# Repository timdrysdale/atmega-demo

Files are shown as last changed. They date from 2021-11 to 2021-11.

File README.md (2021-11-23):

# atmega-demo
PCB to demonstrate atmega microcontroller together with ACS712 and temperature sensor.

## Purpose

This board will be used to monitor power consumption and temperature in remote lab boxes.

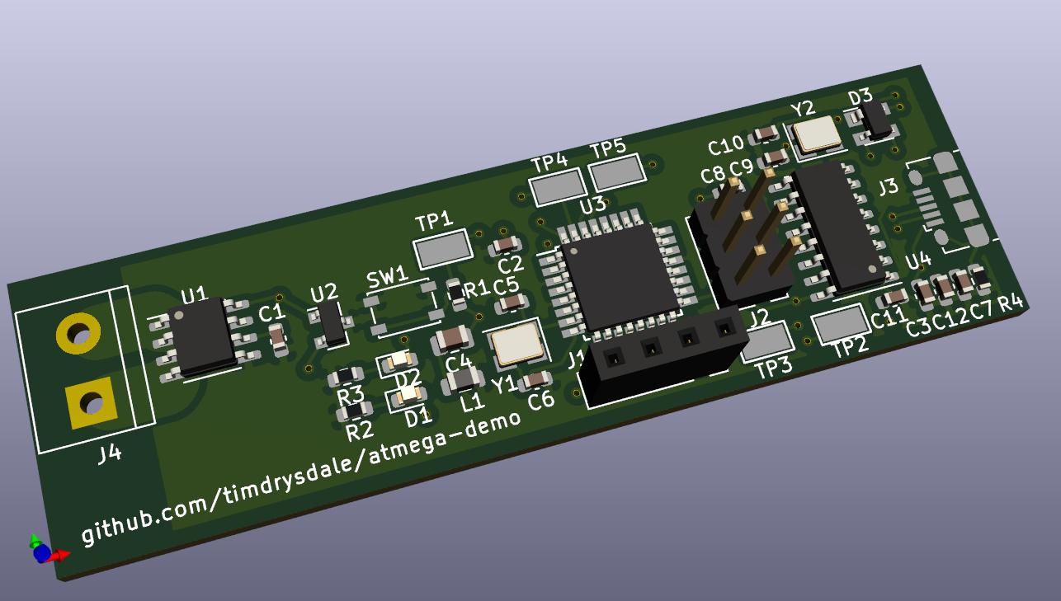
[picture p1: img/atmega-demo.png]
atemga


## Schematic

The key components are an Atmega328P, a CH340 USB transceiver, an ACS712 current sensor and a simple analog temperature sensor. DTR reset is enabled to support re-programming over USB, while ICSP header is supplied for initial programming. Both CH340 and Atmega are using 12MHz crystals, which yields 0.1% baud rate error at 57600 baud for the Atmega.

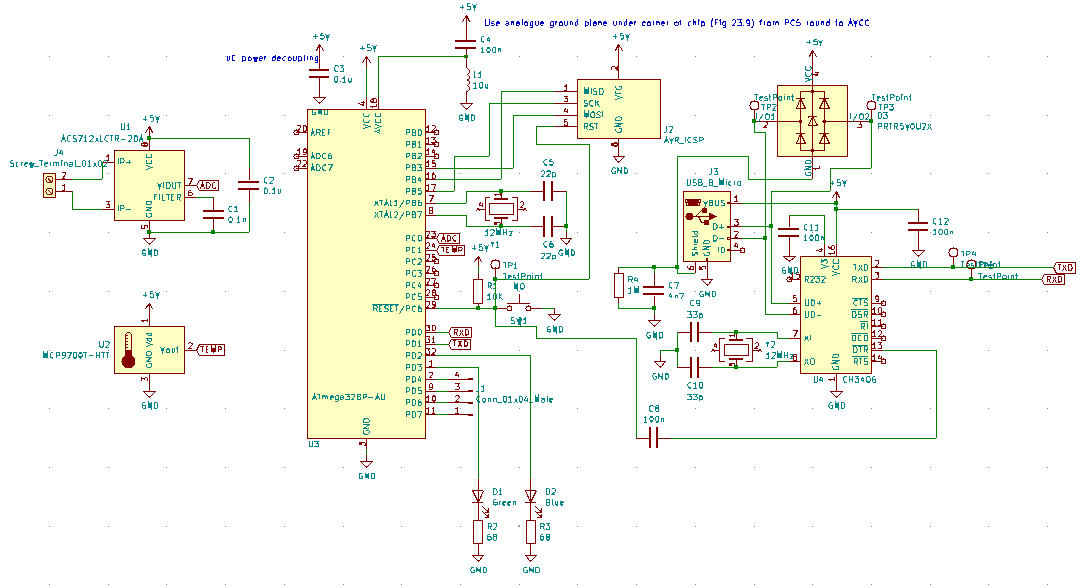
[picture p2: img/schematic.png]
schematic


## BOM

|Comment |Designator |Footprint |LCSC |
|---|---|---|---|
|0.1n |C1 |Capacitor_SMD:C_0603_1608Metric |C100040 |
|100n |C8,C11,C12 |Capacitor_SMD:C_0603_1608Metric |C14663  |
|0.1u |C2,C3 |Capacitor_SMD:C_0603_1608Metric |C14663  |
|100n |C4 |Capacitor_SMD:C_0805_2012Metric |C49678  |
|22p |C5,C6 |Capacitor_SMD:C_0603_1608Metric |C1653 |
|4n7 |C7 |Capacitor_SMD:C_0603_1608Metric |C53987  |
|33p |C9,C10 |Capacitor_SMD:C_0603_1608Metric |C1663 |
|Green |D1 |LED_SMD:LED_0603_1608Metric |C72043  |
|Blue |D2 |LED_SMD:LED_0603_1608Metric |C72043  |
|PRTR5V0U2X |D3 |Package_TO_SOT_SMD:SOT-143 |C2827688|
|Conn_01x04_Male |J1 |Connector_PinSocket_2.54mm:PinSocket_1x04_P2.54mm_Vertical| |
|AVR_ICSP |J2 |Connector_PinHeader_2.54mm:PinHeader_2x03_P2.54mm_Vertical| |
|USB_B_Micro |J3 |Connector_USB:USB_Micro-B_Amphenol_10118194_Horizontal |C132563 |
|Screw_Terminal_01x02|J4 |TerminalBlock:TerminalBlock_bornier-2_P5.08mm | |
|10u |L1 |Inductor_SMD:L_0805_2012Metric |C1046 |
|10K |R1 |Resistor_SMD:R_0603_1608Metric |C25804  |
|68 |R2,R3 |Resistor_SMD:R_0603_1608Metric |C27592  |
|1M |R4 |Resistor_SMD:R_0603_1608Metric |C22935  |
|NO |SW1 |Button_Switch_SMD:SW_SPST_PTS810 |C116501 |
|TestPoint |TP1,TP2,TP3,TP4,TP5|TestPoint:TestPoint_Keystone_5015_Micro-Minature |C238130 |
|ACS712xLCTR-20A |U1 |Package_SO:SOIC-8_3.9x4.9mm_P1.27mm |C10681  |
|MCP9700T-HTT |U2 |Package_TO_SOT_SMD:SOT-23 |C150830 |
|ATmega328P-AU |U3 |Package_QFP:TQFP-32_7x7mm_P0.8mm |C14877  |
|CH340G |U4 |Package_SO:SOIC-16_3.9x9.9mm_P1.27mm |C14267  |
|12MHz |Y1,Y2 |Crystal:Crystal_SMD_3225-4Pin_3.2x2.5mm |C97242  |

## Production

### DFM

The design for manufacture showed a couple of small issues:

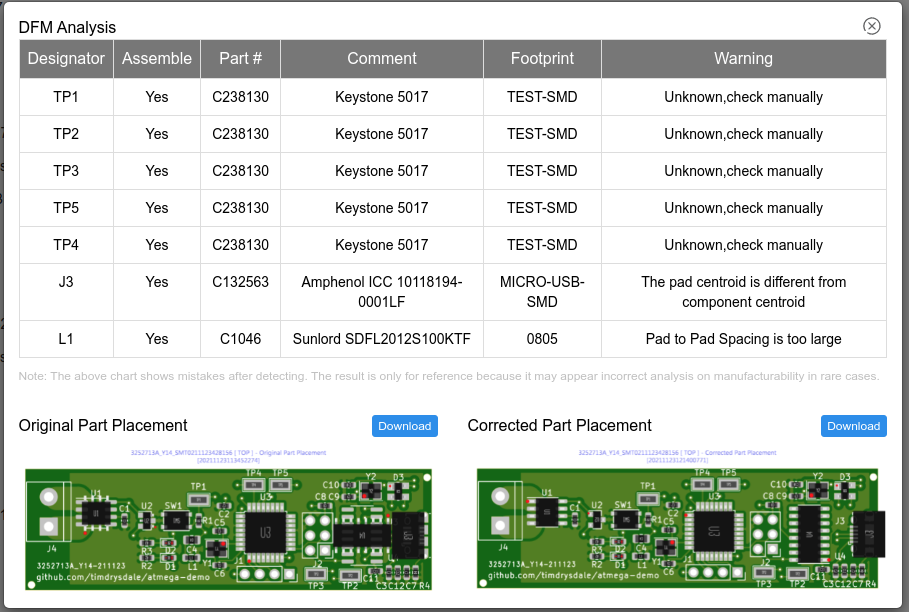
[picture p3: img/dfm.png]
dfm


The parts placement as shown on upload (known to disply with incorrect rotations):

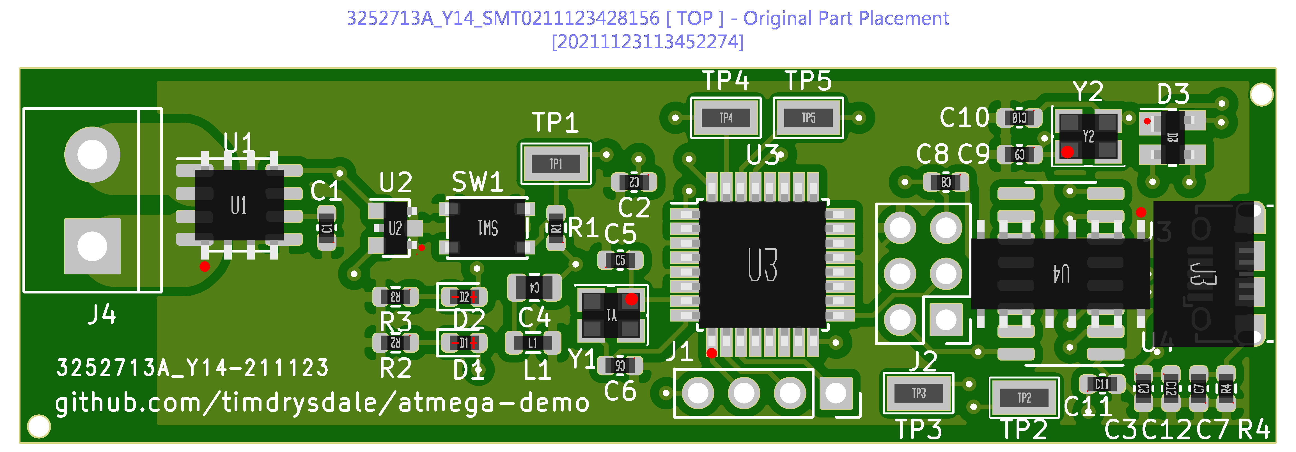
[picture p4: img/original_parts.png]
original_parts


The corrected placement after processing by JLCPCB (parts now oriented the same as the 3D output from KiCAD:

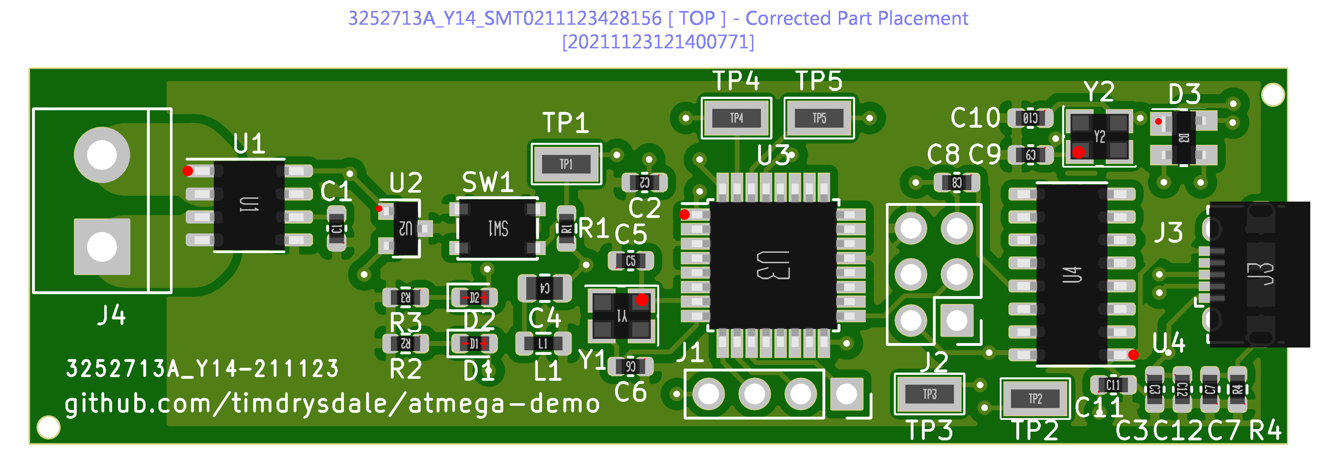
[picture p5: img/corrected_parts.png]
corrected_parts


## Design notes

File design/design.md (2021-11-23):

# DESIGN DESCRIPTION TEMPLATE

## Background

This board is to demonstrate self-assembled Atmega328P circuit.

## Specification

Arduino with USB programming, current sensor, and temp sensor.

Possibly reverse polarity protection, and/or level shifter and external connections headers.

### Design tradeoffs

Note any issues which could be handled in more than one way and justify the approach taken?

### Design for assembly

How will you put it together e.g. if using cable connections, how will these be manufactured?

### Design for reliability

Things go wrong with assembly and usage, even with the best of staff working on the job. So how will your design prevent itself from being damaged by accidental or even malicious misuse, e.g. reversed power supplies, or wrong power supply, incorrect peripheral connections etc (especially where terminal blocks are used, because polarity cannot be enforced very easily).

### Design for maintenance 

What parts are likely to fail, and how will they be replaced?

## Part  details

List here any helpful details which can assist in the review process, such

### Atmega 328P-AU

JLCPCB Part# C14877
Package TQFP-32_7.0x7.0x0.8P
Price ca. $6

KiCAD footprint: Package_QFP:TQFP-32_7x7mm_P0.8mm

Added LCSC code to part in schematic

TXD PD1
RXD PD0

#### Clock

Since want to use USB, need a crystal (else [reported](https://electronics.stackexchange.com/questions/27763/using-the-atmega328-with-the-internal-oscillator) 10% variation in the clock frequency, i.e. outside acceptable range for USB clock speeds.

Internal oscillator calibration procedure is [here](http://projects.gctronic.com/elisa3/AVR053-Calibration-RC-oscillator.pdf) for reference - don't use that for now though.

There are some suggested oscillator frequencies
3.6864MHz (0% error for 230.4k Baud and under)
4.0000MHz (0.2 - 8.5% errors)
7.3728MHz (0% error for 230.4kBaud and under)

Some issues with clocks >8 MHz depending on VCC - to avoid issues, try 4 MHz clock for now?
Arduino uno uses Atmega 328p with 16MHz crystal....

### Oscillator

p146 Table 19.1 has formulae for calculating baud rates.

Async mode, normal rate, BAUD = f_OSC / (16* (UBBRn + 1))

UBBRn has a range from 0 to 4095.

p162 Table 19.9 has some common crystal frequencies

f_OSC= 14.7456 MHz
UBBRn = 15
BAUD = 57k6
Error = 0.0%

Check...

14745600 / (16 * (15+1)) = 57600

Now try a 12MHz crystal ...

guess at UBBRn = 12

12000000/(16*(12+1)) = 57692

Error as per section 19.11

(57692/57600 - 1) * 100%  = 0.1%

0.5% is acceptable, and more than that just affects noise resistance ... so let's try it...

So we can use the same crystal as for the CH340....

#### 3.4 MHz option
Yangxing Tech X49SM36864MSD2SC-1

JLCPCB Part # C2238
Package HC-49S
Description -20℃~70℃ 49SMD ±20ppm 20pF 150Ω 3686400Hz HC-49S/SMD Crystals ROHS
SMT Assembly
Price 6c / min 5
Extended part

#### 14.7MHz option

also good is 14.7456MHz - no errors for most baud rates.

but put in 18pF-22pF caps as suggested [here](https://www.arduino.cc/en/Tutorial/BuiltInExamples/ArduinoToBreadboard)

14.7456MHz oscillator of same package is C240976

### Oscillator capacitors

since 3 - 8 MHz oscillator, Table 8-3 says want 12 - 22pF

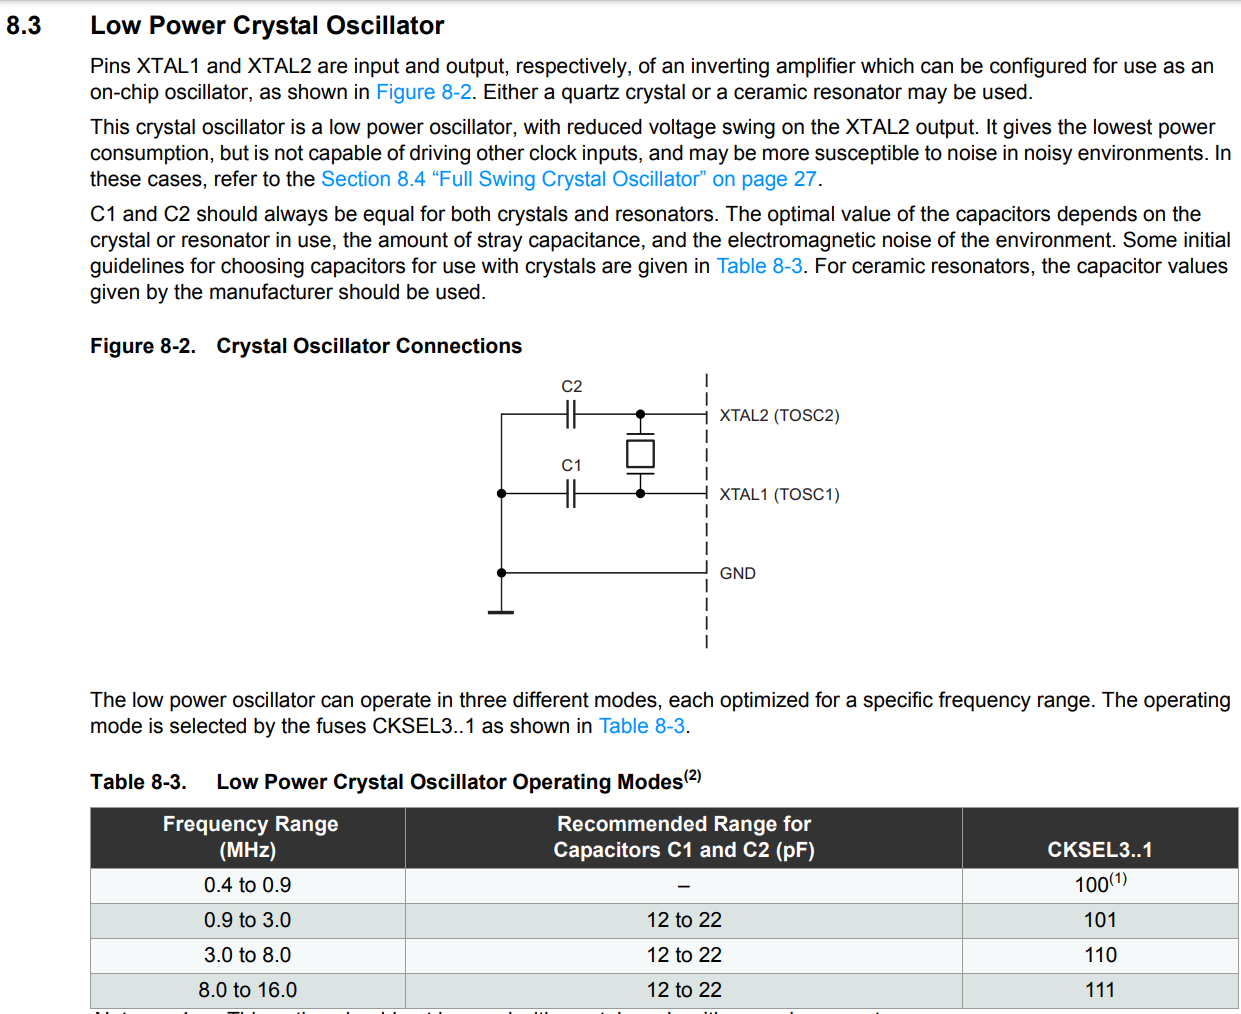
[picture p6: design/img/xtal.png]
xtal


Use 0805 size as lots in stock.

Manufacturer: 0805CG120J500NT

12pF is C1792 Basic part 

Footprint: Capacitor_SMD:C_0805_2012Metric

But upgrade to 18pF for higher frequency crystal, LCSC part: C237185

Upgrade again ... to 22pF because that is what the CH340G needs...
And go to 0603 size seeing as we can.
Manufacturer
Samsung Electro-MechanicsCopy
MFR.Part #
CL10C220JB8NNNCCopy
JLCPCB Part #
C1653Copy
Package
0603Copy
Description
C0G ±5% 50V 22pF 0603 Multilayer Ceramic Capacitors MLCC - SMD/SMT ROHSCopy
Datasheet
Download
Source
JLCPCB
Assembly Type
SMT Assembly
EasyEDA Libraries
PCB Footprint or Symbol

### Reset switch
Manufacturer C&K
MFR.Part # PTS810SJM250SMTRLFS
JLCPCB Part # C116501
Package KEY-SMD
Description Top Actuated 50mA @ 16VDC Round Button SPST SMD Tactile Switches ROHS
Source LCSC
Assembly Type SMT Assembly

Footprint dimensions checked manually
Button_Switch_SMD:SW_SPST_PTS810

### pull up (now changed to 10K)

Revised version: 10K, 0603

Manufacturer
UNI-ROYAL(Uniroyal Elec)Copy
MFR.Part #
0603WAF1002T5ECopy
JLCPCB Part #
C25804Copy
Package
0603Copy
Description
±1% ±100ppm/℃ 10kΩ 0.1W 0603 Chip Resistor - Surface Mount ROHS

First go: 5K
C78980

250mW

0805

### Analog filter

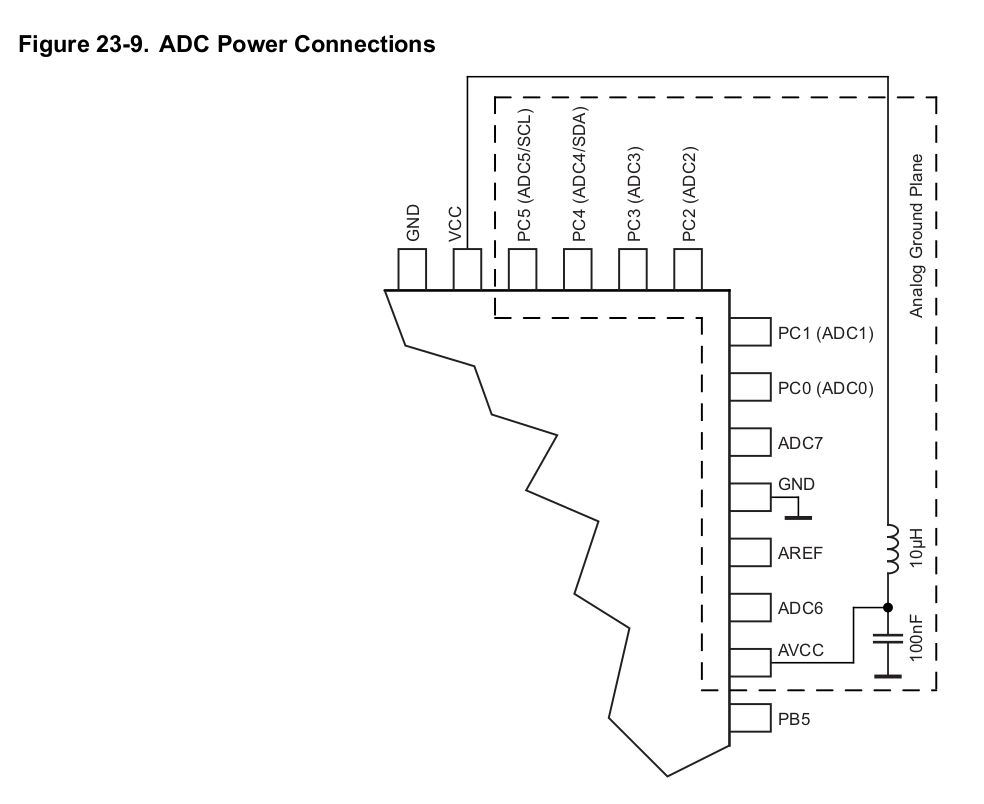
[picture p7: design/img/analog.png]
analog


100nF cap C49678 0805 basic part
footprint:Capacitor_SMD:C_0805_2012Metric

10uH inductor C1046 basic part
(confirmed value by checking part code in table in datasheet SDFL2012S100KTF)
footprint: Inductor_SMD:L_0805_2012Metric

### ICSP header

3x2 2.54mm pitch, programmer such as [this](https://www.pololu.com/product/3172)

Pin 1 MISO
Pin 2 VCC
Pin 3 SCLK
Pin 4 MOSI
Pin 5 RST(negative logic)
Pin 6 GND

Connections: as per datasheet (no connection to XTAL1 says Arduino Uno reference design)
p 254
Table 27-15. Pin Mapping Serial Programming

Symbol Pins I/O Description
MOSI PB3 I Serial data in
MISO PB4 O Serial data out
SCK PB5 I Serial clock

#### CH340

G version in stock

needs crystal of 12MHZ

can we use that for the arduino too, and save a reel fee?

C97242

#### 12 MHz crystal for the USB UART

Manufacturer
TXC CorpCopy
MFR.Part #
7V12000018Copy
JLCPCB Part #
C97242Copy
Package
SMD-3225_4PCopy
Description
12MHz ±30ppm 20pF 100Ω SMD-3225_4P SMD Crystal Resonators RoHSCopy
Datasheet
Download
Source
JLCPCB
Assembly Type
SMT Assembly

This needs either 22pF caps (most examples) or 33pF if powered USB as well. No clear statement as to why has been found in the datasheet yet - but we do it the way it is shown.

Manufacturer
Samsung Electro-MechanicsCopy
MFR.Part #
CL10C330JB8NNNCCopy
JLCPCB Part #
C1663Copy
Package
0603Copy
Description
C0G 33pF ±5% 50V 0603 Multilayer Ceramic Capacitors MLCC - SMD/SMT ROHS

### USB Micro B receptable

The ID pin is mode detect - leave NC for normal peripheral mode, [see here](https://pinouts.ru/PortableDevices/micro_usb_pinout.shtml)

Amphenol ICC
10118194-0001LF
C132563
Connector_USB:USB_Micro-B_Amphenol_1011

### CH340 power caps

0.1uF is 100nF, can get that in 0603

Manufacturer
YAGEOCopy
MFR.Part #
CC0603KRX7R9BB104Copy
JLCPCB Part #
C14663Copy
Package
0603Copy
Description
X7R 100nF ±10% 50V 0603 Multilayer Ceramic Capacitors MLCC - SMD/SMT ROHS

### USB data line protection ....

do we need this with the CH340?? It is ESD, may as well have it.

Manufacturer
NexperiaCopy
MFR.Part #
PRTR5V0U2X,215Copy
JLCPCB Part #
C12333Copy
Package
SOT-143Copy
Description
Unidirectional - - 6V 5.5V SOT-143 ESD Protection Devices ROHSCopy
Datasheet
Download
Source
LCSC

1M resistor

Manufacturer
UNI-ROYAL(Uniroyal Elec)Copy
MFR.Part #
0603WAF1004T5ECopy
JLCPCB Part #
C22935Copy
Package
0603Copy
Description
1MΩ ±1% ±100ppm/℃ 0.1W 0603 Chip Resistor - Surface Mount ROHSCopy
Datasheet
Download
Source
JLCPCB
Assembly Type
SMT Assembly

#### USB connection to Atmega
see o70 Table 13-9
PD1 TXD (USART output pin)
PD0 RXD (USART input pin)

#### Test point

KeystoneCopy
MFR.Part #
5017Copy
JLCPCB Part #
C238130Copy
Package
TEST-SMDCopy
Description
SMD Test Points/Test Rings ROHS

This has hte same footprint as the keystone 5015 micro miniature

TestPoint:TestPoint_Keystone_5015_Micro-Minature (3.43mm by 1.78mm)

#### ACS712

Manufacturer
Allegro MicroSystems, LLCCopy
MFR.Part #
ACS712ELCTR-20A-TCopy
JLCPCB Part #
C10681Copy
Package
SOIC-8_3.9x4.9x1.27PCopy
Description
SOIC-8_150mil Current Sensors ROHSCopy
Datasheet
Download
Source
JLCPCB

needs 100n decoupler (same as otheres)

an 1n filter 

Manufacturer
YAGEOCopy
MFR.Part #
CC0603KRX7R9BB102Copy
JLCPCB Part #
C100040Copy
Package
0603Copy
Description
X7R 1nF ±10% 50V 0603 Multilayer Ceramic Capacitors MLCC - SMD/SMT ROHSCopy
Datasheet
Download
Source
LCSC
Assembly Type
SMT Assembly

### LEDS

0603 

need 68Ohm ballast at 5V

C27592

Manufacturer
UNI-ROYAL(Uniroyal Elec)Copy
MFR.Part #
0603WAF680JT5ECopy
JLCPCB Part #
C27592Copy
Package
0603Copy
Description
±1% ±200ppm/℃ 68Ω 0.1W 0603 Chip Resistor - Surface Mount ROHS

#### Temp sensor

Manufacturer
Microchip TechCopy
MFR.Part #
MCP9701AT-E/TTCopy
JLCPCB Part #
C150830Copy
Package
SOT-23-3Copy
Description
-10°C ~ 125°C - Analog, Local 19.5mV/°C Analog Voltage SOT-23(SOT-23-3) Temperature Sensors ROHS

#### Sourcing

Where can you get it from?

#### Size, orientation

How big is it, and which way round does the footprint need to be on the PCB? How much clearance is needed around the part e.g. for putting in wires to terminal blocks

#### Supply considerations

What is the typical, and absolute supply voltage(s)?

#### Application considerations

What supporting components are needed? 

#### Electromagnetic compatibility considerations

Note any components which should be close together, far apart, and any track length considerations

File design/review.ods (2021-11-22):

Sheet: Summary
Item | Status | Checks OK | Issues
PCB | ISSUES | 21/22 | CHECK: Overall size?;
Example Part | ISSUES | /13 | CHECK: Power supply given; CHECK: Ground given; CHECK: Unused inputs treated ok?; CHECK: Special track sizing?; CHECK: Footprint size correct?; CHECK: Footprint orientation?; CHECK: EMC considerations?; CHECK: ROHS; CHECK: Assembly considerations?5 ; CHECK: Footprint source?; CHECK: Footprint license?; CHECK: Who will supply?; CHECK: Who will assemble?;

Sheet: Board
PART0 | PCB
STATUS | ISSUES
CHECKS | 21/22
ISSUES | CHECK: Overall size?;
CHECKS |  | Do check? | OK? | Result? | Comment
CHECK: How many layers? | OK, 2 | TRUE | TRUE | OK
CHECK: What thickness copper? | Ok, 1oz | TRUE | TRUE | OK
CHECK: What type of processes? | Ok, Lead Free, PTH | TRUE | TRUE | OK
CHECK: What layers are needed in the Gerbers? | Ok, need top and bottom copper – they will figure out which need to be PTH | TRUE | TRUE | OK
CHECK: What sort of drill sizing? | Ok, Assume 0.1mm sizes available | TRUE | TRUE | OK
CHECK: Mounting Holes? | Ok, 4xM3 clearance (3.2mm) | TRUE | TRUE | OK
CHECK: Board materials? | Ok, FR4 | TRUE | TRUE | OK
CHECK: Board thickness? | Ok, 1.6mm | TRUE | TRUE | OK
CHECK: Overall size? |  | TRUE | FALSE | ISSUE | CHECK: Overall size?;
CHECK: Quantity needed? | OK, 12 | TRUE | TRUE | OK
CHECK: Spares needed? | OK, 8 | TRUE | TRUE | OK
CHECK: EMC issues considered? | Ok – not really | TRUE | TRUE | OK
CHECK: Thermal issues considered? | Ok, Yes – power track size for terminal blocks, no currents sensor now so rest is low temp; also the motor driver as current sensing which is sensitive to over temperature, and/or we know what current represents too much current in the drivers (the library | TRUE | TRUE | OK
CHECK: Sourcing issues considered? | Ok, Yes – jlbpcb stocks checked for parts to be used in assembly | TRUE | TRUE | OK
CHECK: Assembly issues considered? | Ok, Yes – moved terminals so can get wires in easily, left out through hole test points. | TRUE | TRUE | OK
CHECK: Testing issues considered? | Ok, Added test points and ground plane pads for scope clips | TRUE | TRUE | OK
CHECK: PCB fits in enclosure ok? | Ok, Enclosure will be about 50mm high (false floor in iso container, so we have clearance) | TRUE | TRUE | OK
CHECK: Test points & type? | OK, push on so will need to hold probes in place – good enough for a design we already tested | TRUE | TRUE | OK
CHECK: Ground clip location? | Ok, edges of the boards, clear of other components | TRUE | TRUE | OK
CHECK: ROHS | Ok – presumably | TRUE | TRUE | OK
 |  | FALSE | FALSE | IGNORE
 |  | FALSE | FALSE | IGNORE
WHO? |  | FALSE | FALSE | IGNORE
CHECK: Who will supply? | ok, JLCPCB | TRUE | TRUE | OK
Quantity |  | FALSE | FALSE | IGNORE
Price per unit |  | FALSE | FALSE | IGNORE
Date last checked? |  | FALSE | FALSE | IGNORE
CHECK: Who will assemble? | ok, JLCPCB and us for some through hole items | TRUE | TRUE | OK
 |  | FALSE | FALSE | IGNORE
OTHER? |  | FALSE | FALSE | IGNORE
Notes |  | 22 | 21 | ISSUES
0: Copy this template sheet and rename it as appropriate to each part in the design.
1: Status: use, avoid, deleted: it is useful to note parts which have been considered and should not be used (just in case we get the same bright idea again later, let’s remember why it’s not a bright idea afterall)
2: Note anything relevant to choosing this design – or not choosing it! e.g. fast enough to do level shifting on high speed bus
3: Package type: surface mount / through hole (i.e. which assembly processes are needed?)
4: Lifecycle status: prototype/current/discontinued? is the part listed as ok for new designs? If not, choose another part.
5: orientation, pick & place constraints, clearances, fits, tolerances

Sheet: Atmega328P-AU
PART0 | Atmega 328P-AU
STATUS | ISSUES
CHECKS | 2/17
ISSUES | CHECK: Power supply given; CHECK: Ground given; CHECK: Unused inputs treated ok?; CHECK: Special track sizing?; CHECK: Footprint size correct?; CHECK: Footprint orientation?; CHECK: EMC considerations?; CHECK: Analogue ground plane as per Fig 23-9; CHECK: LC network for AVCC?; CHECK: ROHS; CHECK: Assembly considerations?5 ; CHECK: Footprint source?; CHECK: Footprint license?; CHECK: Who will supply?; CHECK: Who will assemble?;
CHECKS |  | Do check? | OK? | Result? | Comment
Power supply wanted |  | FALSE | FALSE | IGNORE
CHECK: Power supply given |  | TRUE | FALSE | ISSUE | CHECK: Power supply given; | 0
Ground wanted |  | FALSE | FALSE | IGNORE
CHECK: Ground given |  | TRUE | FALSE | ISSUE | CHECK: Ground given;
List unused inputs |  | FALSE | FALSE | IGNORE
CHECK: Unused inputs treated ok? |  | TRUE | FALSE | ISSUE | CHECK: Unused inputs treated ok?;
CHECK: Special track sizing? |  | TRUE | FALSE | ISSUE | CHECK: Special track sizing?;
CHECK: Footprint size correct? |  | TRUE | FALSE | ISSUE | CHECK: Footprint size correct?;
CHECK: Footprint orientation? |  | TRUE | FALSE | ISSUE | CHECK: Footprint orientation?;
Nearest component? |  | FALSE | FALSE | IGNORE
CHECK: EMC considerations? |  | TRUE | FALSE | ISSUE | CHECK: EMC considerations?;
CHECK: Analogue ground plane as per Fig 23-9 |  | TRUE | FALSE | ISSUE | CHECK: Analogue ground plane as per Fig 23-9;
CHECK: Normally open reset with pullup? | OK | TRUE | TRUE | OK
CHECK: Xtal oscillator suitable for power, and with caps? | OK | TRUE | TRUE | OK
CHECK: LC network for AVCC? |  | TRUE | FALSE | ISSUE | CHECK: LC network for AVCC?;
 |  | FALSE | FALSE | IGNORE
 |  | FALSE | FALSE | IGNORE
 |  | FALSE | FALSE | IGNORE
WHAT |  | FALSE | FALSE | IGNORE
Name |  | FALSE | FALSE | IGNORE
Part # |  | FALSE | FALSE | IGNORE
Manufacturer |  | FALSE | FALSE | IGNORE
Approx Price |  | FALSE | FALSE | IGNORE
Package type?3 |  | FALSE | FALSE | IGNORE
Datasheet link |  | FALSE | FALSE | IGNORE
 |  | FALSE | FALSE | IGNORE
WHY |  | FALSE | FALSE | IGNORE
Purpose |  | FALSE | FALSE | IGNORE
Design justification2 |  | FALSE | FALSE | IGNORE
Lifecycle status?4 |  | FALSE | FALSE | IGNORE
CHECK: ROHS |  | TRUE | FALSE | ISSUE | CHECK: ROHS;
 |  | FALSE | FALSE | IGNORE
HOW? |  | FALSE | FALSE | IGNORE
Supply Typical range |  | FALSE | FALSE | IGNORE
Supply Abs max |  | FALSE | FALSE | IGNORE
Supply Abs Min |  | FALSE | FALSE | IGNORE
What to do with unused inputs? |  | FALSE | FALSE | IGNORE
CHECK: Assembly considerations?5 |  | TRUE | FALSE | ISSUE | CHECK: Assembly considerations?5 ;
CHECK: Footprint source? |  | TRUE | FALSE | ISSUE | CHECK: Footprint source?;
CHECK: Footprint license? |  | TRUE | FALSE | ISSUE | CHECK: Footprint license?;
 |  | FALSE | FALSE | IGNORE
WHO? |  | FALSE | FALSE | IGNORE
CHECK: Who will supply? |  | TRUE | FALSE | ISSUE | CHECK: Who will supply?;
Stock level |  | FALSE | FALSE | IGNORE
Price per unit |  | FALSE | FALSE | IGNORE
MoQ |  | FALSE | FALSE | IGNORE
Date last checked? |  | FALSE | FALSE | IGNORE
CHECK: Who will assemble? |  | TRUE | FALSE | ISSUE | CHECK: Who will assemble?;
 |  | FALSE | FALSE | IGNORE
OTHER? |  | FALSE | FALSE | IGNORE
Dimensions |  | FALSE | FALSE | IGNORE
Notes |  | 17 | 2 | ISSUES
0: Copy this template sheet and rename it as appropriate to each part in the design.
1: Status: use, avoid, deleted: it is useful to note parts which have been considered and should not be used (just in case we get the same bright idea again later, let’s remember why it’s not a bright idea afterall)
2: Note anything relevant to choosing this design – or not choosing it! e.g. fast enough to do level shifting on high speed bus
3: Package type: surface mount / through hole (i.e. which assembly processes are needed?)
4: Lifecycle status: prototype/current/discontinued? is the part listed as ok for new designs? If not, choose another part.
5: orientation, pick & place constraints, clearances, fits, tolerances

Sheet: ExamplePart
PART0 | Example Part
STATUS | ISSUES
CHECKS | /13
ISSUES | CHECK: Power supply given; CHECK: Ground given; CHECK: Unused inputs treated ok?; CHECK: Special track sizing?; CHECK: Footprint size correct?; CHECK: Footprint orientation?; CHECK: EMC considerations?; CHECK: ROHS; CHECK: Assembly considerations?5 ; CHECK: Footprint source?; CHECK: Footprint license?; CHECK: Who will supply?; CHECK: Who will assemble?;
CHECKS |  | Do check? | OK? | Result? | Comment
Power supply wanted |  | FALSE | FALSE | IGNORE
CHECK: Power supply given |  | TRUE | FALSE | ISSUE | CHECK: Power supply given; | 0
Ground wanted |  | FALSE | FALSE | IGNORE
CHECK: Ground given |  | TRUE | FALSE | ISSUE | CHECK: Ground given;
List unused inputs |  | FALSE | FALSE | IGNORE
CHECK: Unused inputs treated ok? |  | TRUE | FALSE | ISSUE | CHECK: Unused inputs treated ok?;
CHECK: Special track sizing? |  | TRUE | FALSE | ISSUE | CHECK: Special track sizing?;
CHECK: Footprint size correct? |  | TRUE | FALSE | ISSUE | CHECK: Footprint size correct?;
CHECK: Footprint orientation? |  | TRUE | FALSE | ISSUE | CHECK: Footprint orientation?;
Nearest component? |  | FALSE | FALSE | IGNORE
CHECK: EMC considerations? |  | TRUE | FALSE | ISSUE | CHECK: EMC considerations?;
 |  | FALSE | FALSE | IGNORE
 |  | FALSE | FALSE | IGNORE
 |  | FALSE | FALSE | IGNORE
 |  | FALSE | FALSE | IGNORE
 |  | FALSE | FALSE | IGNORE
 |  | FALSE | FALSE | IGNORE
 |  | FALSE | FALSE | IGNORE
WHAT |  | FALSE | FALSE | IGNORE
Name |  | FALSE | FALSE | IGNORE
Part # |  | FALSE | FALSE | IGNORE
Manufacturer |  | FALSE | FALSE | IGNORE
Approx Price |  | FALSE | FALSE | IGNORE
Package type?3 |  | FALSE | FALSE | IGNORE
Datasheet link |  | FALSE | FALSE | IGNORE
 |  | FALSE | FALSE | IGNORE
WHY |  | FALSE | FALSE | IGNORE
Purpose |  | FALSE | FALSE | IGNORE
Design justification2 |  | FALSE | FALSE | IGNORE
Lifecycle status?4 |  | FALSE | FALSE | IGNORE
CHECK: ROHS |  | TRUE | FALSE | ISSUE | CHECK: ROHS;
 |  | FALSE | FALSE | IGNORE
HOW? |  | FALSE | FALSE | IGNORE
Supply Typical range |  | FALSE | FALSE | IGNORE
Supply Abs max |  | FALSE | FALSE | IGNORE
Supply Abs Min |  | FALSE | FALSE | IGNORE
What to do with unused inputs? |  | FALSE | FALSE | IGNORE
CHECK: Assembly considerations?5 |  | TRUE | FALSE | ISSUE | CHECK: Assembly considerations?5 ;
CHECK: Footprint source? |  | TRUE | FALSE | ISSUE | CHECK: Footprint source?;
CHECK: Footprint license? |  | TRUE | FALSE | ISSUE | CHECK: Footprint license?;
 |  | FALSE | FALSE | IGNORE
WHO? |  | FALSE | FALSE | IGNORE
CHECK: Who will supply? |  | TRUE | FALSE | ISSUE | CHECK: Who will supply?;
Stock level |  | FALSE | FALSE | IGNORE
Price per unit |  | FALSE | FALSE | IGNORE
MoQ |  | FALSE | FALSE | IGNORE
Date last checked? |  | FALSE | FALSE | IGNORE
CHECK: Who will assemble? |  | TRUE | FALSE | ISSUE | CHECK: Who will assemble?;
 |  | FALSE | FALSE | IGNORE
OTHER? |  | FALSE | FALSE | IGNORE
Dimensions |  | FALSE | FALSE | IGNORE
Notes |  | 13 | 0 | ISSUES
0: Copy this template sheet and rename it as appropriate to each part in the design.
1: Status: use, avoid, deleted: it is useful to note parts which have been considered and should not be used (just in case we get the same bright idea again later, let’s remember why it’s not a bright idea afterall)
2: Note anything relevant to choosing this design – or not choosing it! e.g. fast enough to do level shifting on high speed bus
3: Package type: surface mount / through hole (i.e. which assembly processes are needed?)
4: Lifecycle status: prototype/current/discontinued? is the part listed as ok for new designs? If not, choose another part.
5: orientation, pick & place constraints, clearances, fits, tolerances
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

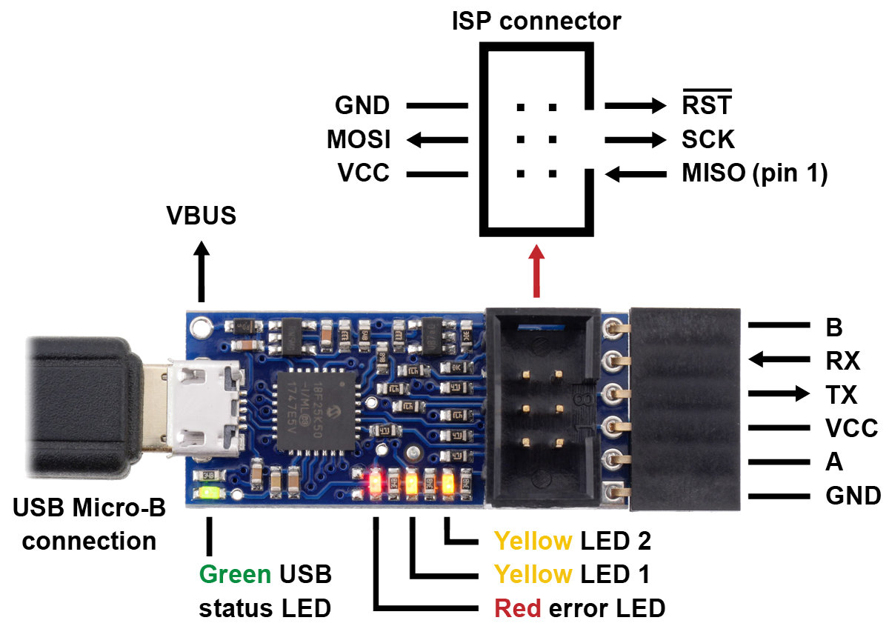
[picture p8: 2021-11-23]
design/img/0J8587.1200.jpg

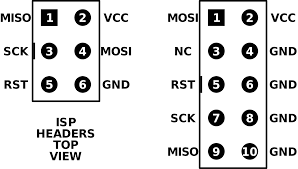
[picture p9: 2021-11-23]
design/img/header.png

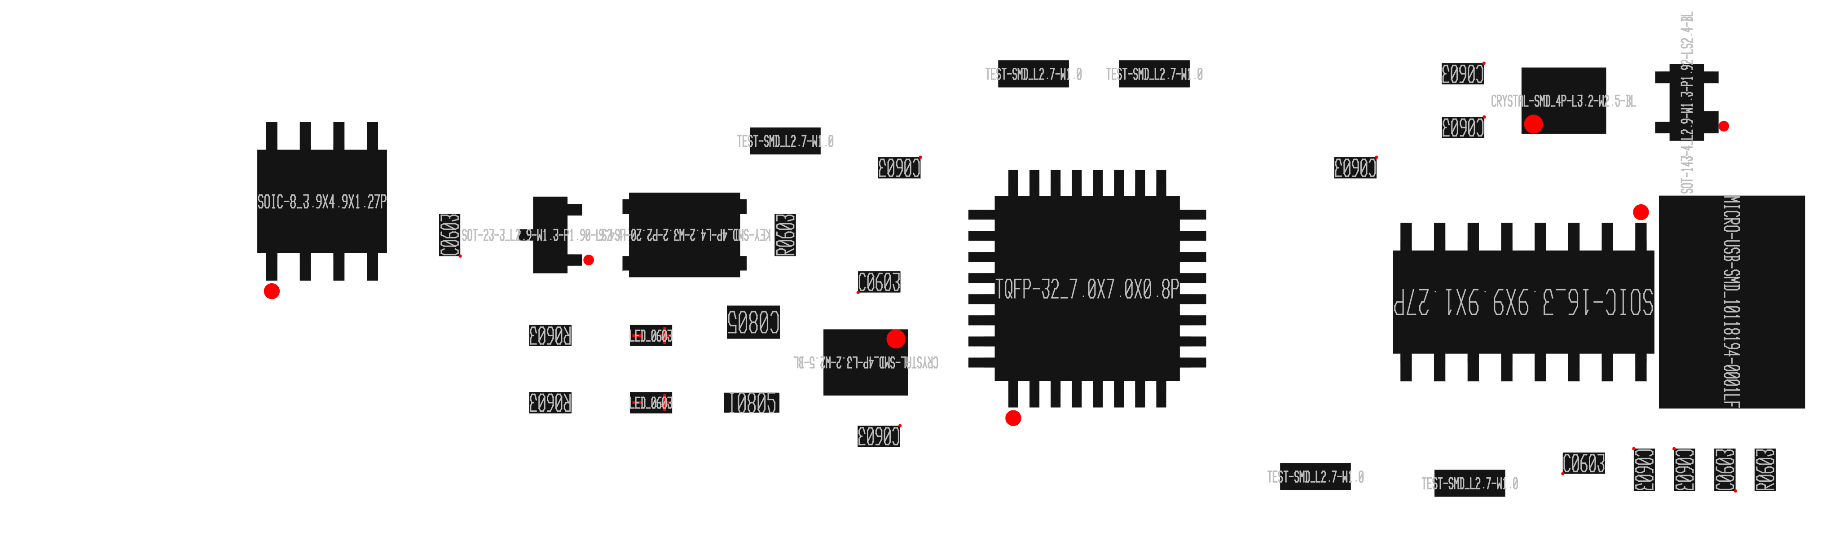
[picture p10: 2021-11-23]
img/orientation_bw.png

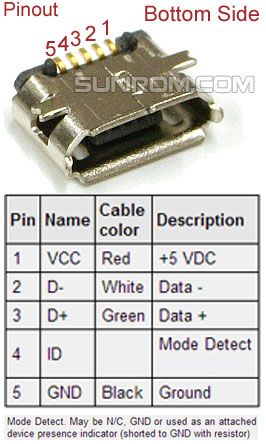
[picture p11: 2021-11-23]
doc/0404bbed587454b5a5733fb191808ea9.jpg

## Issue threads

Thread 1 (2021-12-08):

swap TXD,RXD pins on CH340

timdrysdale, 2021-12-08:
The CH340 works with the pins the other way round to what you might think .... RXD goes to TX and vice versa. See [here](https://github.com/UnfinishedStuff/CH340C). This has been verified with a board hack to cut the lines to vias from TP4, TP5 and connect TP4 to the via that used to be connected to TP5, and vice versa. Then USB serial transmission works in both directions, as evidenced by an echo program.

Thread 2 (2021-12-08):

12MHz bootloader

timdrysdale, 2021-12-08:
Saving an extended component fee by selecting 12MHz crystal has complicated setting up a bootloader.

This is not quite resolved yet.

Recompiling the bootloader causes this issue
https://forum.arduino.cc/t/optiboot-issue-avrdude-error-address-0x8010-out-of-range/863387

```
atmega328_12: TARGET = atmega328_12
atmega328_12: MCU_TARGET = atmega328p
atmega328_12: CFLAGS += '-DLED_START_FLASHES=3' '-DBAUD_RATE=115200'
atmega328_12: AVR_FREQ = 12000000L
atmega328_12: LDSECTIONS  = -Wl,--section-start=.text=0x7e00 -Wl,--section-start=.version=0x7ffe
atmega328_12: $(PROGRAM)_atmega328_12.hex
atmega328_12: $(PROGRAM)_atmega328_12.lst

atmega328_isp_12: atmega328
atmega328_isp_12: TARGET = atmega328_12
atmega328_isp_12: MCU_TARGET = atmega328p
# 512 byte boot, SPIEN
atmega328_isp_12: HFUSE = DE
# Low power xtal (12MHz) 12KCK/14CK+65ms
atmega328_isp_12: LFUSE = FF
# 2.7V brownout
atmega328_isp_12: EFUSE = 05
atmega328_isp_12: isp
```

boards.txt
```
tim.name=Tim

tim.upload.tool=avrdude
tim.upload.protocol=arduino

tim.bootloader.tool=avrdude
tim.bootloader.unlock_bits=0x3F
tim.bootloader.lock_bits=0x0F

tim.build.f_cpu=12000000L
tim.build.board=AVR_NANO
tim.build.core=arduino
tim.build.variant=eightanaloginputs

## Arduino Tim w/ ATmega328P
## --------------------------
tim.menu.cpu.atmega328=ATmega328P

tim.menu.cpu.atmega328.upload.maximum_size=30720
tim.menu.cpu.atmega328.upload.maximum_data_size=2048
tim.menu.cpu.atmega328.upload.speed=115200

tim.menu.cpu.atmega328.bootloader.low_fuses=0xFF
tim.menu.cpu.atmega328.bootloader.high_fuses=0xDA
tim.menu.cpu.atmega328.bootloader.extended_fuses=0xFD
tim.menu.cpu.atmega328.bootloader.file=optiboot/optiboot_atmega328_12.hex

tim.menu.cpu.atmega328.build.mcu=atmega328p
```

timdrysdale, 2021-12-08:
Solution - use the minicore bootloader. Access this via the boards manager (need to add minicore to board manager URLs first) see README for [minicore](https://github.com/MCUdude/MiniCore)

Default settings for atmega328 except choose external crystal 12MHz. Verified that can upload sketches when the hardware hack in #1 is applied.

Closed 2021-12-08.

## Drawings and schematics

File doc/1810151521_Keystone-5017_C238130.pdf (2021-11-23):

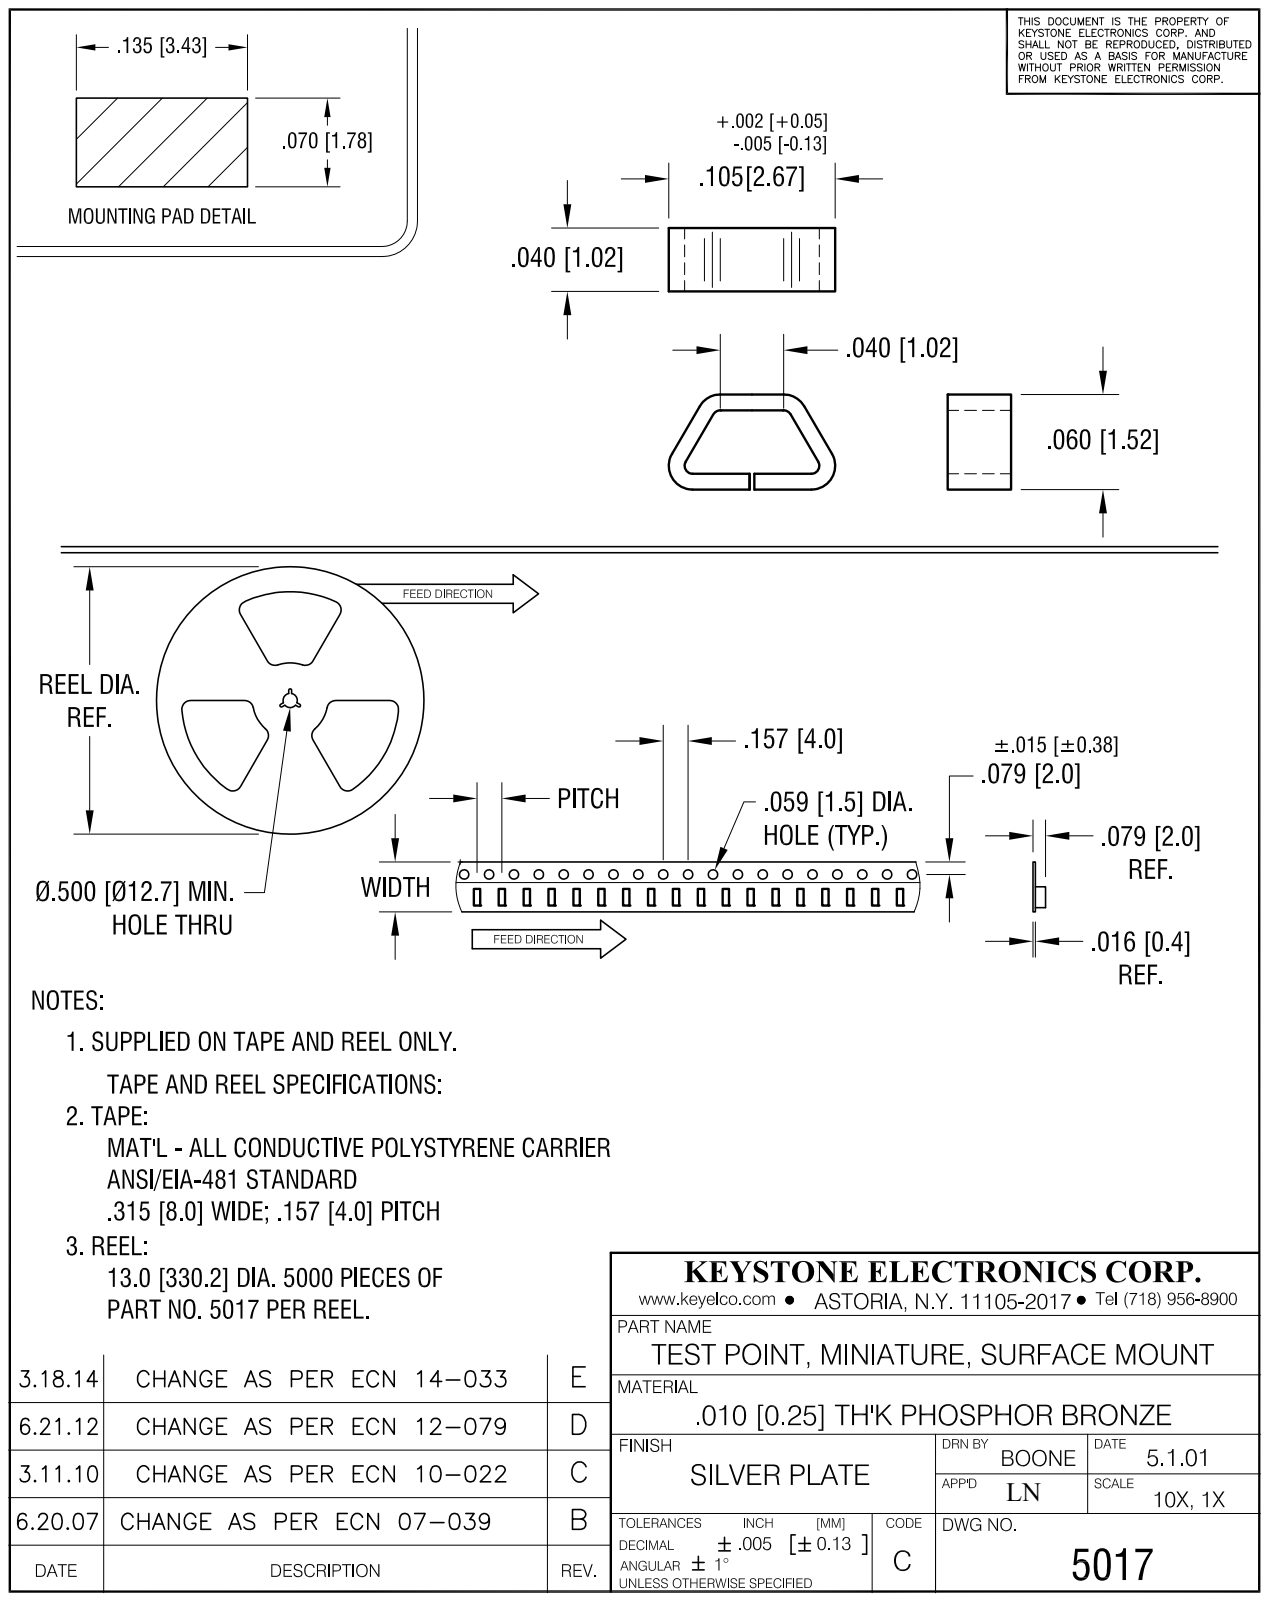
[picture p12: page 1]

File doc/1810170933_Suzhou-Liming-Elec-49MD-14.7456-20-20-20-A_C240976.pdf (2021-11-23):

# 49MD 系列

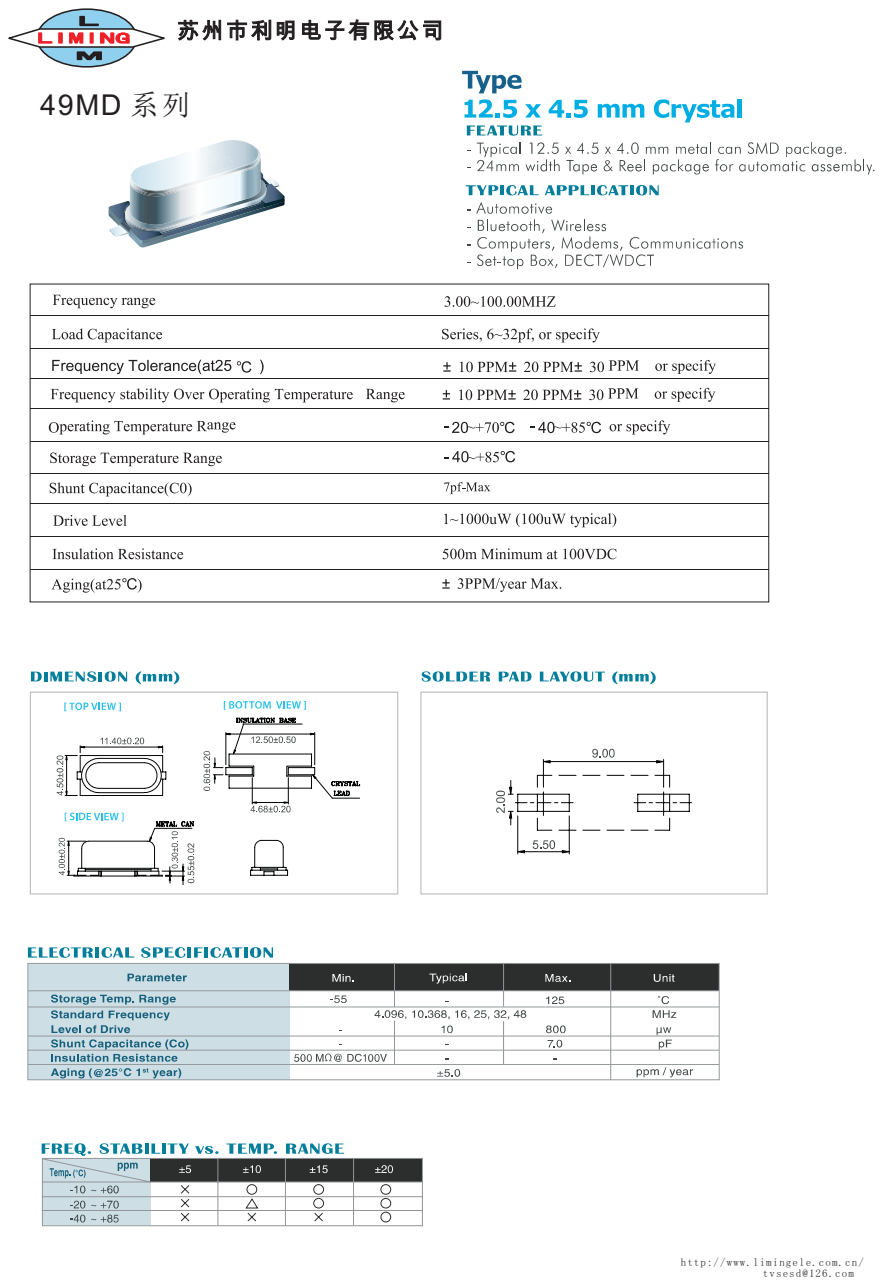
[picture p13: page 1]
tvsesd@126.com

http://www.limingele.com.cn/

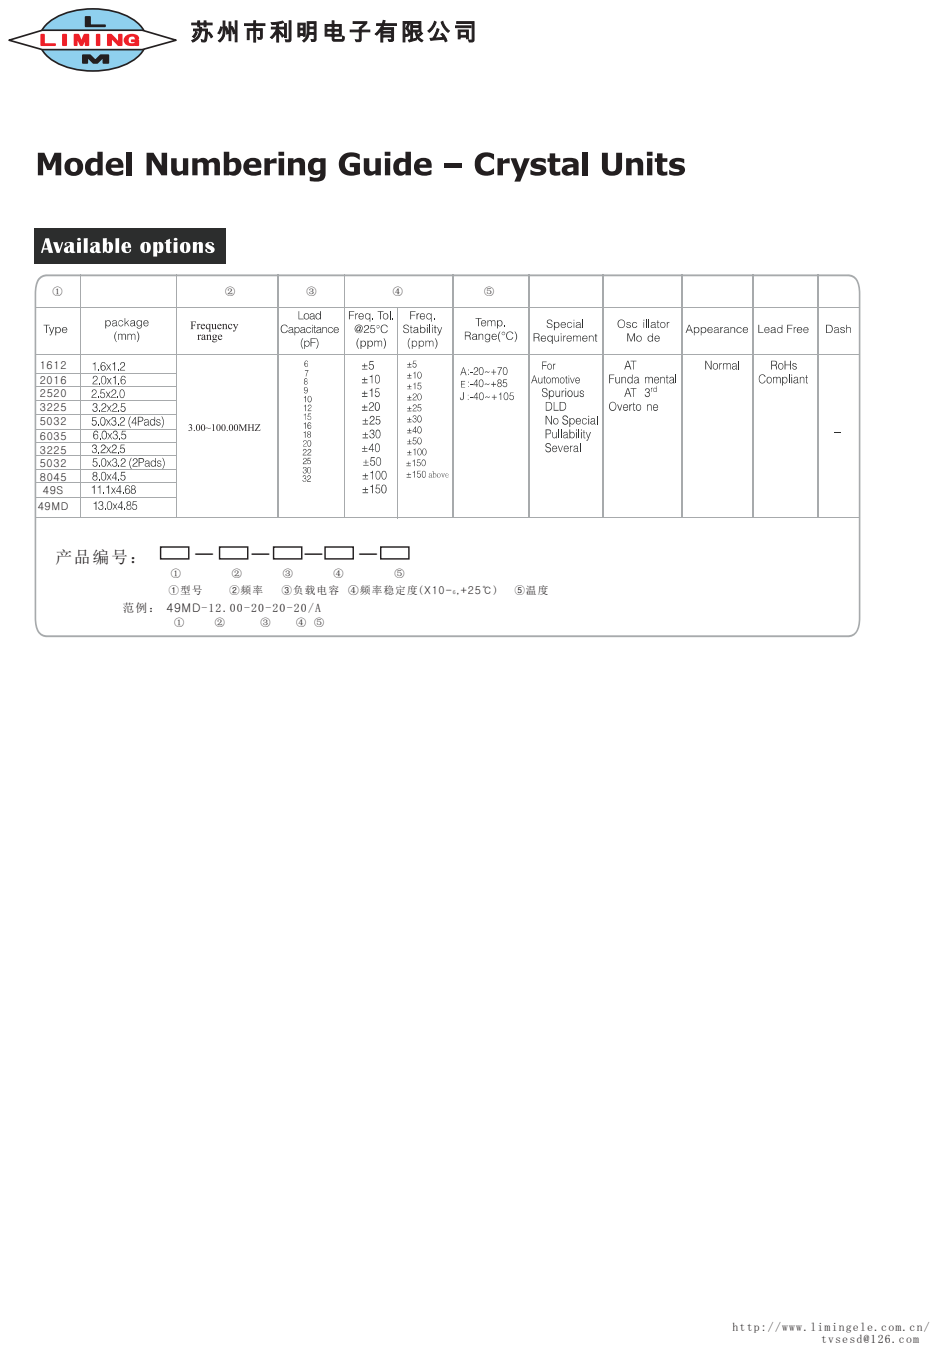
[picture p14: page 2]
tvsesd@126.com; ①型号; ②频率; ③负载电容; ④频率稳定度(X10-6,+25℃); ⑤温度; 产品编号：

http://www.limingele.com.cn/

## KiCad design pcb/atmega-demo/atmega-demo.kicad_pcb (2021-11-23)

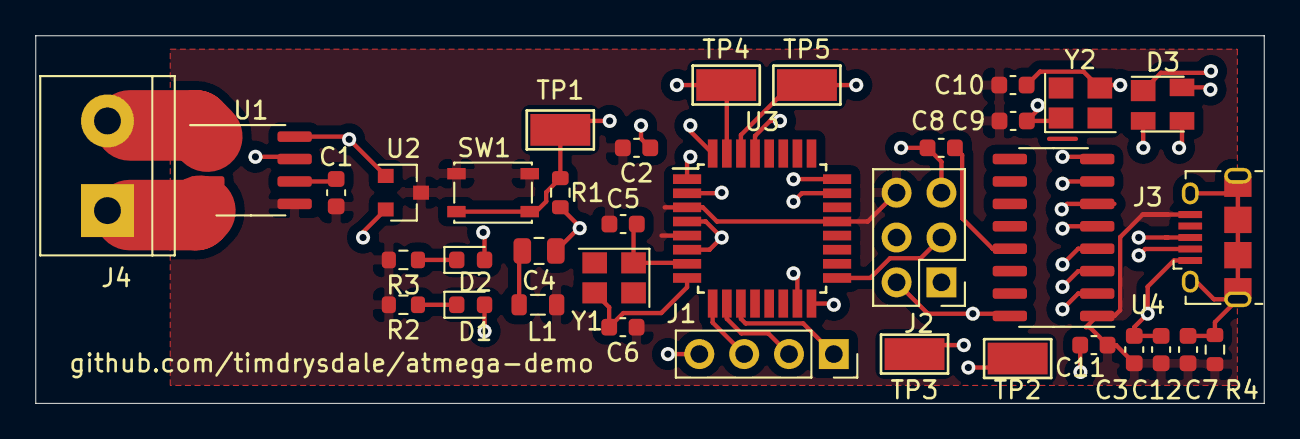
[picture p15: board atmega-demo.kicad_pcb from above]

Board: 4 copper layers, 69.6 x 20.8 mm, 36 parts (0 on the bottom side), 31 nets.

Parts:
C1: 0.1n; C_0603_1608Metric
C2, C3: 0.1u; C_0603_1608Metric
C4: 100n; C_0805_2012Metric
C5, C6: 22p; C_0603_1608Metric
C7: 4n7; C_0603_1608Metric
C8, C11, C12: 100n; C_0603_1608Metric
C9, C10: 33p; C_0603_1608Metric
D1: Green; LED_0603_1608Metric
D2: Blue; LED_0603_1608Metric
D3: PRTR5V0U2X; SOT-143
J1: Conn_01x04_Male; PinSocket_1x04_P2.54mm_Vertical
J2: AVR_ICSP; PinHeader_2x03_P2.54mm_Vertical
J3: USB_B_Micro; USB_Micro-B_Amphenol_10118194_Horizontal
J4: Screw_Terminal_01x02; TerminalBlock_bornier-2_P5.08mm
L1: 10u; L_0805_2012Metric
R1: 10K; R_0603_1608Metric
R2, R3: 68; R_0603_1608Metric
R4: 1M; R_0603_1608Metric
SW1: NO; SW_SPST_PTS810
TP1, TP2, TP3, TP4, TP5: TestPoint; TestPoint_Keystone_5015_Micro-Minature
U1: ACS712xLCTR-20A; SOIC-8_3.9x4.9mm_P1.27mm
U2: MCP9700T-HTT; SOT-23
U3: ATmega328P-AU; TQFP-32_7x7mm_P0.8mm
U4: CH340G; SOIC-16_3.9x9.9mm_P1.27mm
Y1, Y2: 12MHz; Crystal_SMD_3225-4Pin_3.2x2.5mm

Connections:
+5V: C2.1, C3.1, C4.1, C12.1, D3.4, J2.2, J3.1, R1.1, U1.8, U2.1, U3.4, U3.6, U4.16
ADC: U1.7, U3.23
GND: C1.1, C2.2, C3.2, C5.1, C6.1, C7.1, C9.2, C10.2, C11.2, C12.2, J2.6, J3.5, L1.2, R2.2, R3.2, R4.1, SW1.2, U1.5, U2.3, U3.3, U3.5, U3.21, U4.1
unnamed: C1.2, U1.6
unnamed: C4.2, L1.1
unnamed: C5.2, U3.7, Y1.1
unnamed: C6.2, U3.8, Y1.3
unnamed: C7.2, D3.1, J3.6, R4.2
unnamed: C8.1, U4.13
unnamed: C8.2, J2.5, R1.2, SW1.1, TP1.1, U3.29
unnamed: C9.1, U4.7, Y2.1
unnamed: C10.1, U4.8, Y2.3
unnamed: C11.1, U4.4
unnamed: D1.1, R2.1
unnamed: D1.2, U3.1
unnamed: D2.1, R3.1
unnamed: D2.2, U3.32
unnamed: D3.2, J3.2, TP2.1, U4.6
unnamed: D3.3, J3.3, TP3.1, U4.5
unnamed: J1.1, U3.11
unnamed: J1.2, U3.10
unnamed: J1.3, U3.9
unnamed: J1.4, U3.2
unnamed: J2.1, U3.16
unnamed: J2.3, U3.17
unnamed: J2.4, U3.15
unnamed: J4.1, U1.3, U1.4
unnamed: J4.2, U1.1, U1.2
RXD: TP5.1, U3.30, U4.3
TEMP: U2.2, U3.24
TXD: TP4.1, U3.31, U4.2

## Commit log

2021-11-22 Initial design commit with 0805 and 3.6MHz osc
    [atmega-demo.kicad_pcb, atmega-demo.sch, review.ods]
2021-11-23 Design as ordered
    [atmega-demo-B_Cu.gbl, atmega-demo-B_Mask.gbs, atmega-demo-B_Paste.gbp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]
